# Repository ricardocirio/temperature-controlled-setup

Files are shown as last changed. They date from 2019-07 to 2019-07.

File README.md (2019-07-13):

# Temperature controlled setup

## About

This repository contains documentation for assembling a low-cost heating system designed for manufacturing and characterization of gas sensors, including dedicated hardware and firmware, comprising a proportional-integral-derivative controller and user interface for its use. The hardware consists of a printed circuit board containing an analog-to-digital converter (LTC2439) for temperature measurements acquired by thermocouples and a microcontroller (ATmega328P) that coordinates the entire process running a finite-state machine.

## Hardware

Full schematics may be found [here](./hardware/schematics.pdf). PCB's Kicad project is under the *hardware* folder.

<p align="center" float="left">
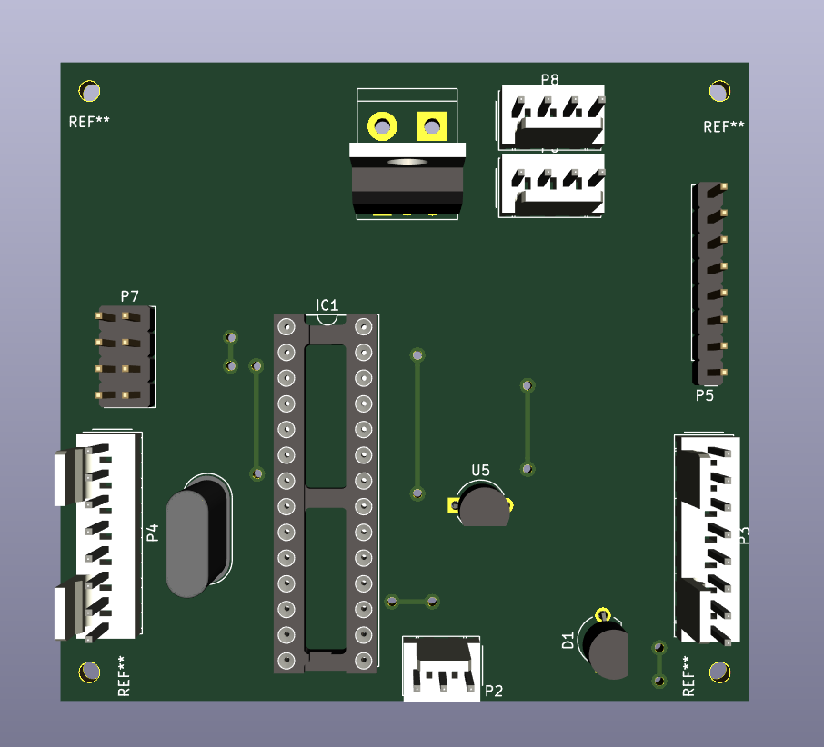
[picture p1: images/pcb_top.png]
PCB top
	
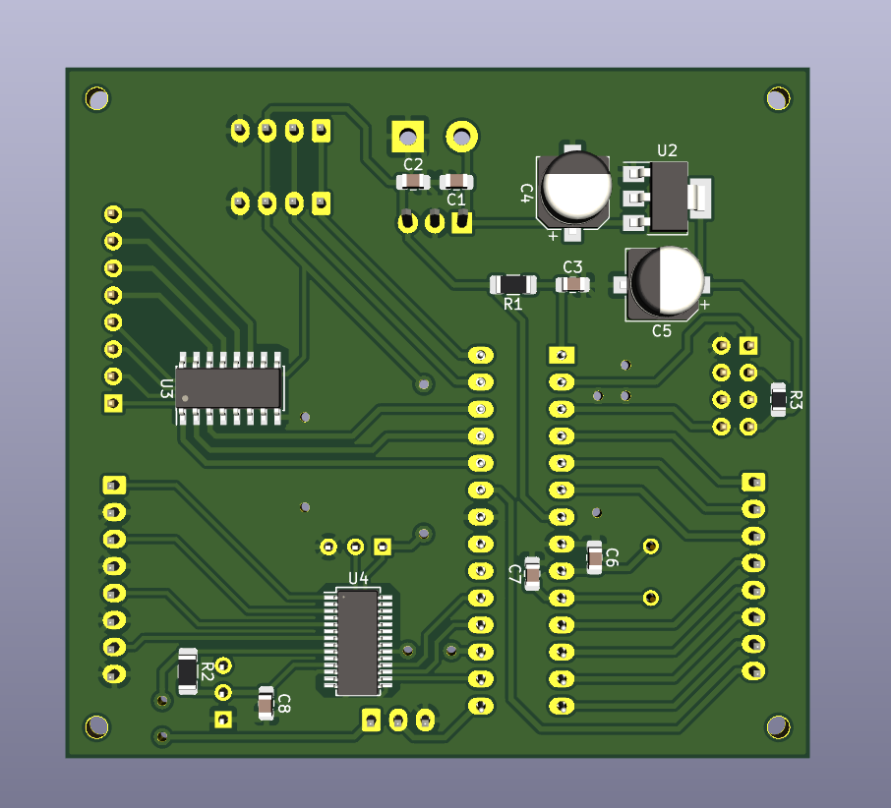
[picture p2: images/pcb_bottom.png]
PCB bottom
	
</p>

## Authors

* Ricardo Cirio<br>
* Leticia Matos<br>
* Fernando Miranda<br>
* Daniel Lohmann

Sponsor: CNPq n° 04/2018.



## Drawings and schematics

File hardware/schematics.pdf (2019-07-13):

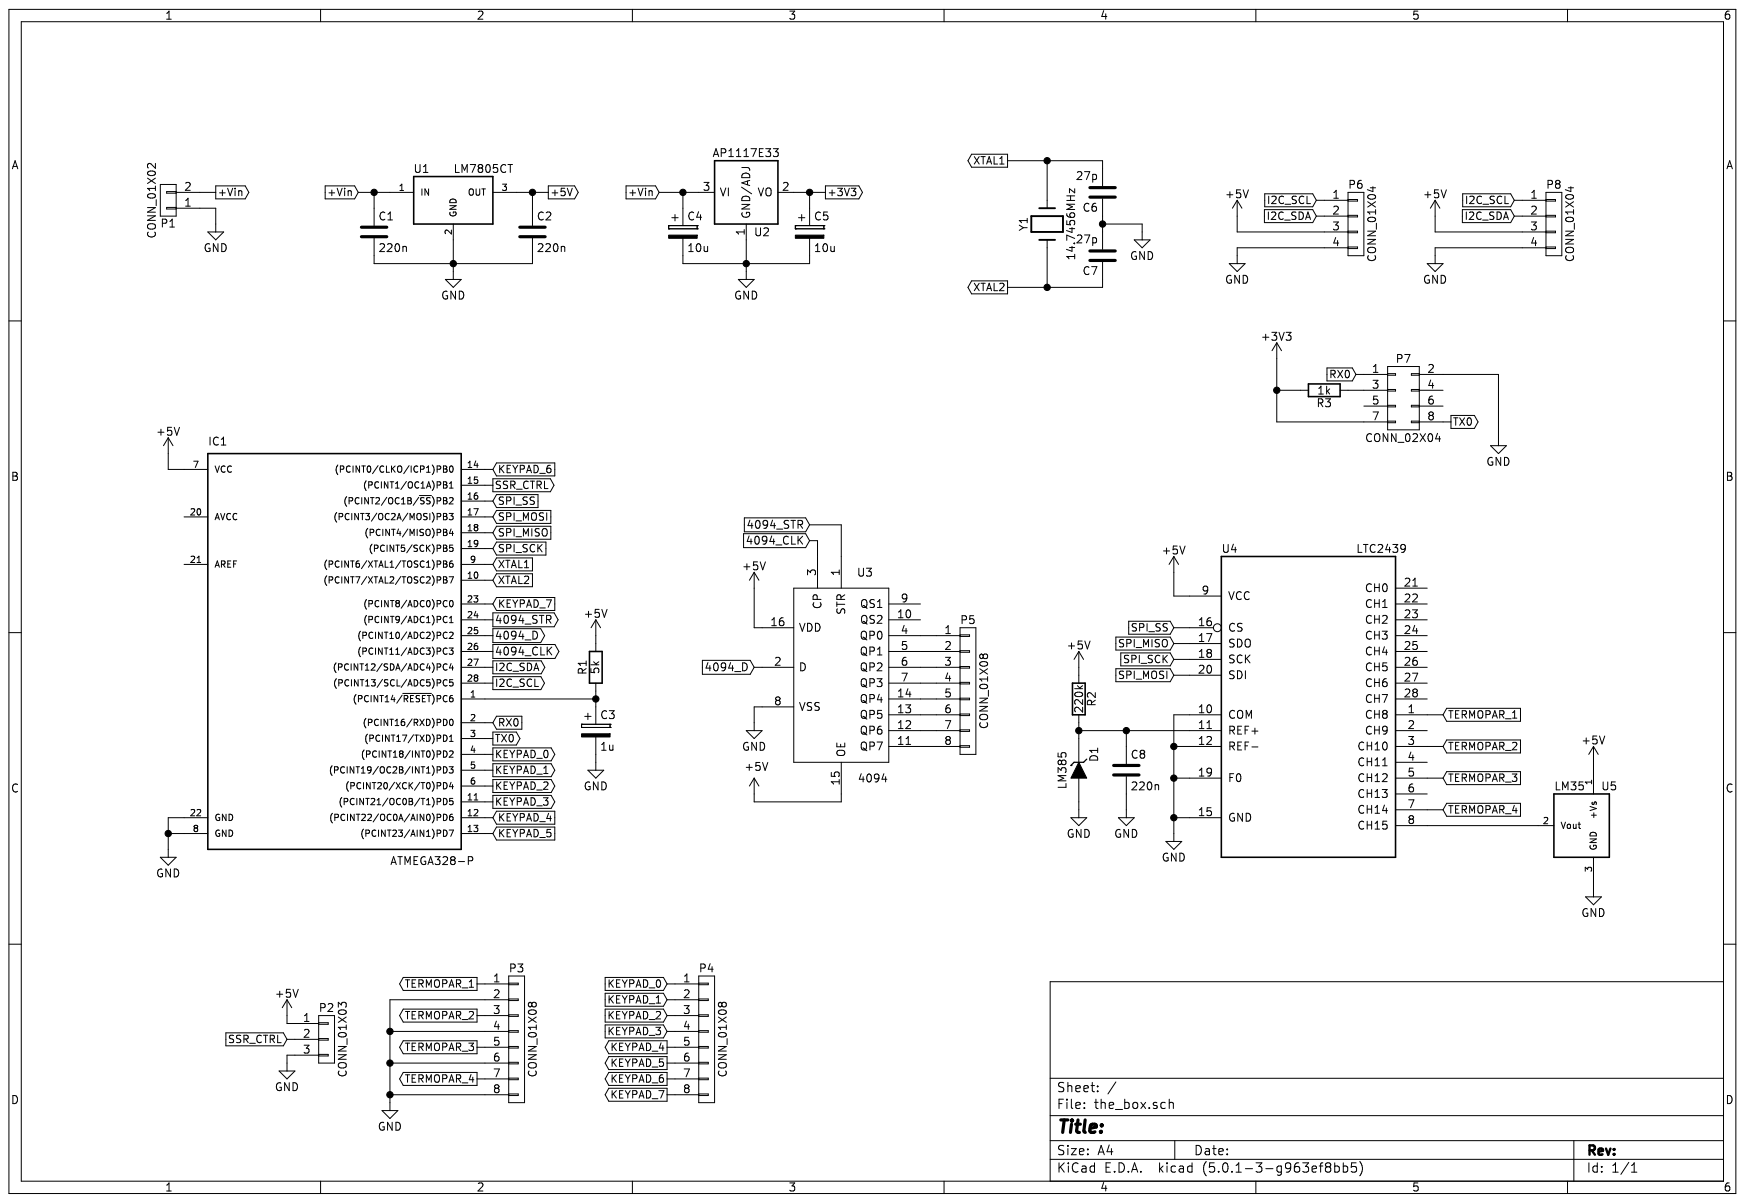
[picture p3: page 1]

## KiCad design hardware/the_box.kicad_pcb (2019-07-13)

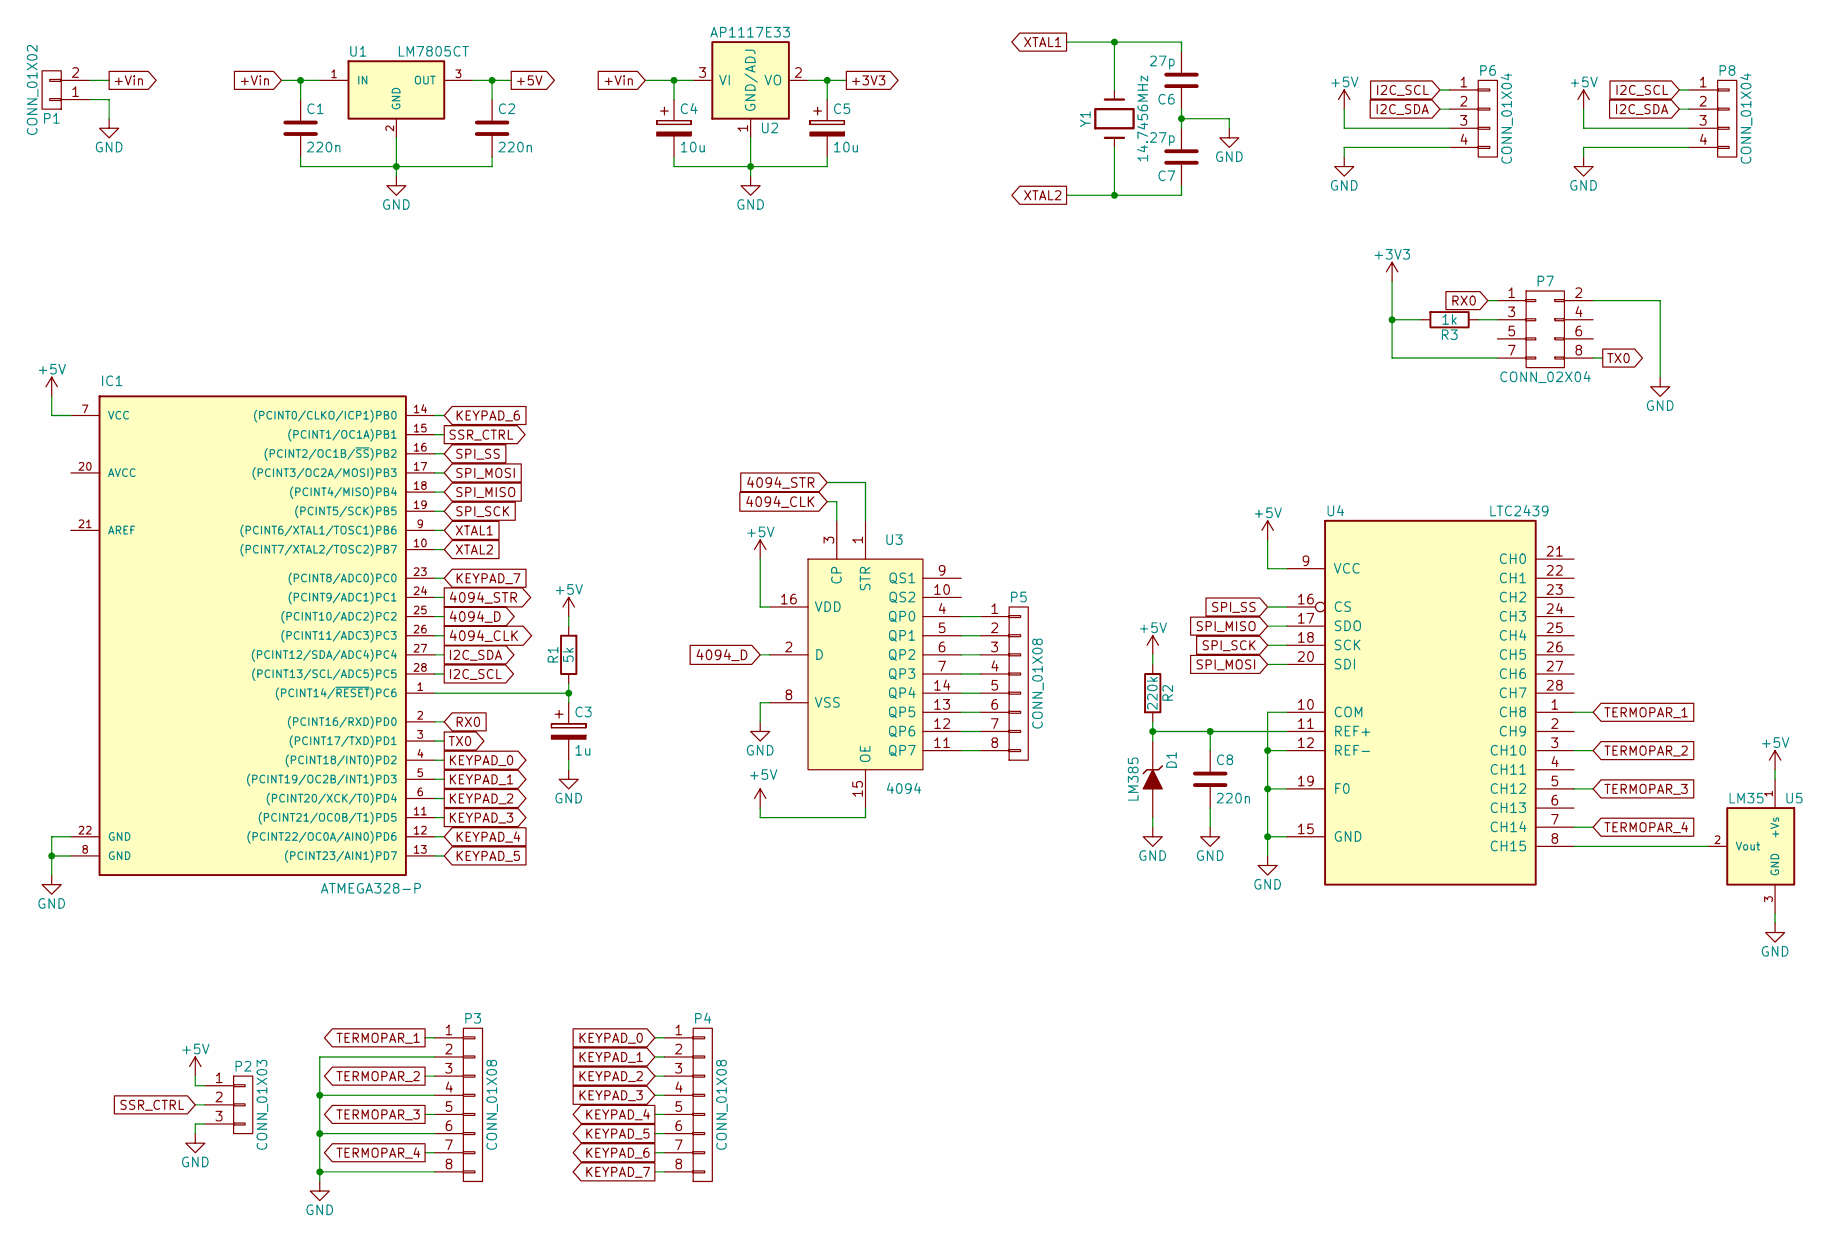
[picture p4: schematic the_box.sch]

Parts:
C1, C2, C8: 220n; C_0805_2012Metric_Pad1.15x1.40mm_HandSolder
C3: 1u; C_0805_2012Metric_Pad1.15x1.40mm_HandSolder
C4, C5: 10u; CP_Elec_6.3x5.3
C6, C7: 27p; C_0805_2012Metric_Pad1.15x1.40mm_HandSolder
D1: LM385; TO-92_Inline_Wide
IC1: ATMEGA328-P; DIP-28_W7.62mm_Socket_LongPads
P1: CONN_01X02; TerminalBlock_bornier-2_P5.08mm
P2: CONN_01X03; Molex_KK-254_AE-6410-03A_1x03_P2.54mm_Vertical
P3, P4: CONN_01X08; Molex_KK-254_AE-6410-08A_1x08_P2.54mm_Vertical
P5: CONN_01X08; PinHeader_1x08_P2.54mm_Vertical
P6, P8: CONN_01X04; Molex_KK-254_AE-6410-04A_1x04_P2.54mm_Vertical
P7: CONN_02X04; PinHeader_2x04_P2.54mm_Vertical
R1: 5k; R_1206_3216Metric_Pad1.42x1.75mm_HandSolder
R2: 220k; R_1206_3216Metric_Pad1.42x1.75mm_HandSolder
R3: 1k; R_0805_2012Metric_Pad1.15x1.40mm_HandSolder
U1: LM7805CT; TO-220-3_Vertical
U2: AP1117E33; SOT-223-3_TabPin2
U3: 4094; SOIC-16_3.9x9.9mm_P1.27mm
U4: LTC2439; SSOP-28_3.9x9.9mm_P0.635mm
U5: LM35; TO-92_Inline_Wide
Y1: 14.7456MHz; Crystal_HC49-U_Vertical

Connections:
4094_CLK: IC1.26 ((PCINT11/ADC3)PC3), U3.3 (CP)
4094_D: IC1.25 ((PCINT10/ADC2)PC2), U3.2 (D)
4094_STR: IC1.24 ((PCINT9/ADC1)PC1), U3.1 (STR)
+3V3: C5.1, P7.7, R3.2, U2.2 (VO)
+5V: C2.1, IC1.7 (VCC), P2.1, P6.3, P8.3, R1.2, R2.1, U1.3 (OUT), U3.15 (OE), U3.16 (VDD), U4.9 (VCC), U5.1 (+Vs)
+Vin: C1.1, C4.1, P1.2, U1.1 (IN), U2.3 (VI)
GND: C1.2, C2.2, C3.2, C4.2, C5.2, C6.1, C7.2, C8.2, D1.1 (A), IC1.8 (GND), IC1.22 (GND), P1.1, P2.3, P3.2, P3.4, P3.6, P3.8, P6.4, P7.2, P8.4, U1.2 (GND), U2.1 (GND/ADJ), U3.8 (VSS), U4.10 (COM), U4.12 (REF-), U4.15 (GND), U4.19 (F0), U5.3 (GND)
I2C_SCL: IC1.28 ((PCINT13/SCL/ADC5)PC5), P6.1, P8.1
I2C_SDA: IC1.27 ((PCINT12/SDA/ADC4)PC4), P6.2, P8.2
KEYPAD_0: IC1.4 ((PCINT18/INT0)PD2), P4.1
KEYPAD_1: IC1.5 ((PCINT19/OC2B/INT1)PD3), P4.2
KEYPAD_2: IC1.6 ((PCINT20/XCK/T0)PD4), P4.3
KEYPAD_3: IC1.11 ((PCINT21/OC0B/T1)PD5), P4.4
KEYPAD_4: IC1.12 ((PCINT22/OC0A/AIN0)PD6), P4.5
KEYPAD_5: IC1.13 ((PCINT23/AIN1)PD7), P4.6
KEYPAD_6: IC1.14 ((PCINT0/CLKO/ICP1)PB0), P4.7
KEYPAD_7: IC1.23 ((PCINT8/ADC0)PC0), P4.8
unnamed: C3.1, IC1.1 ((PCINT14/~RESET~)PC6), R1.1
unnamed: C8.1, D1.2 (K), R2.2, U4.11 (REF+)
unnamed: P5.1, U3.4 (QP0)
unnamed: P5.2, U3.5 (QP1)
unnamed: P5.3, U3.6 (QP2)
unnamed: P5.4, U3.7 (QP3)
unnamed: P5.5, U3.14 (QP4)
unnamed: P5.6, U3.13 (QP5)
unnamed: P5.7, U3.12 (QP6)
unnamed: P5.8, U3.11 (QP7)
unnamed: P7.3, R3.1
unnamed: U4.8 (CH15), U5.2 (Vout)
RX0: IC1.2 ((PCINT16/RXD)PD0), P7.1
SPI_MISO: IC1.18 ((PCINT4/MISO)PB4), U4.17 (SDO)
SPI_MOSI: IC1.17 ((PCINT3/OC2A/MOSI)PB3), U4.20 (SDI)
SPI_SCK: IC1.19 ((PCINT5/SCK)PB5), U4.18 (SCK)
SPI_SS: IC1.16 ((PCINT2/OC1B/~SS~)PB2), U4.16 (CS)
SSR_CTRL: IC1.15 ((PCINT1/OC1A)PB1), P2.2
TERMOPAR_1: P3.1, U4.1 (CH8)
TERMOPAR_2: P3.3, U4.3 (CH10)
TERMOPAR_3: P3.5, U4.5 (CH12)
TERMOPAR_4: P3.7, U4.7 (CH14)
TX0: IC1.3 ((PCINT17/TXD)PD1), P7.8
XTAL1: C6.2, IC1.9 ((PCINT6/XTAL1/TOSC1)PB6), Y1.2
XTAL2: C7.1, IC1.10 ((PCINT7/XTAL2/TOSC2)PB7), Y1.1

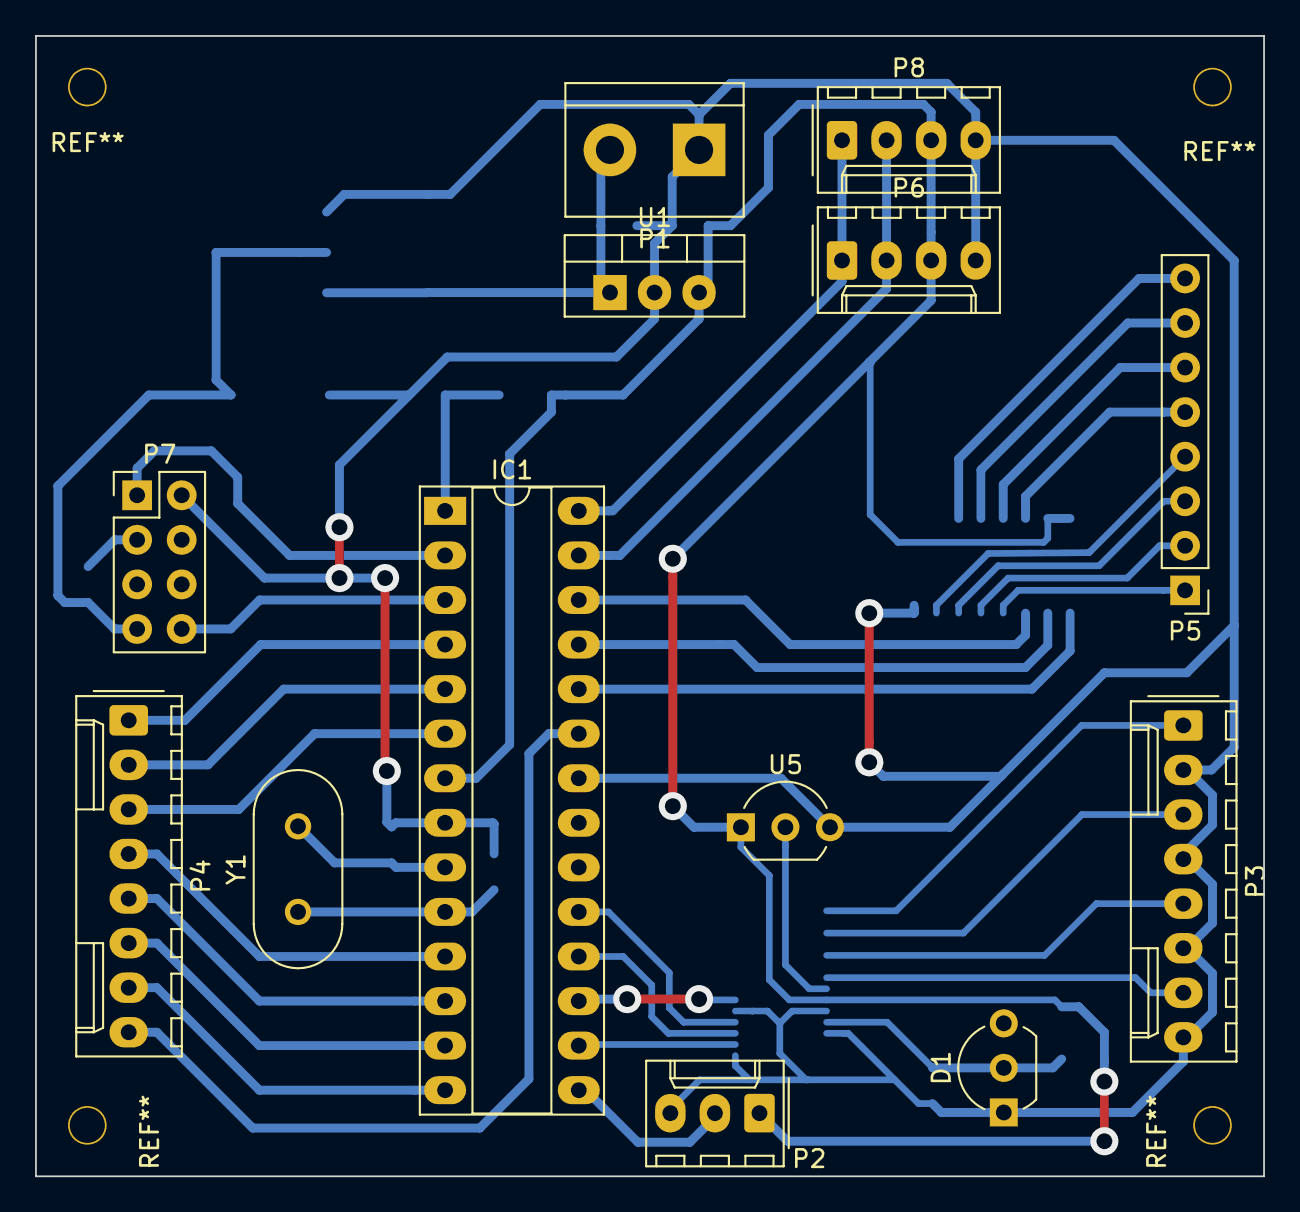
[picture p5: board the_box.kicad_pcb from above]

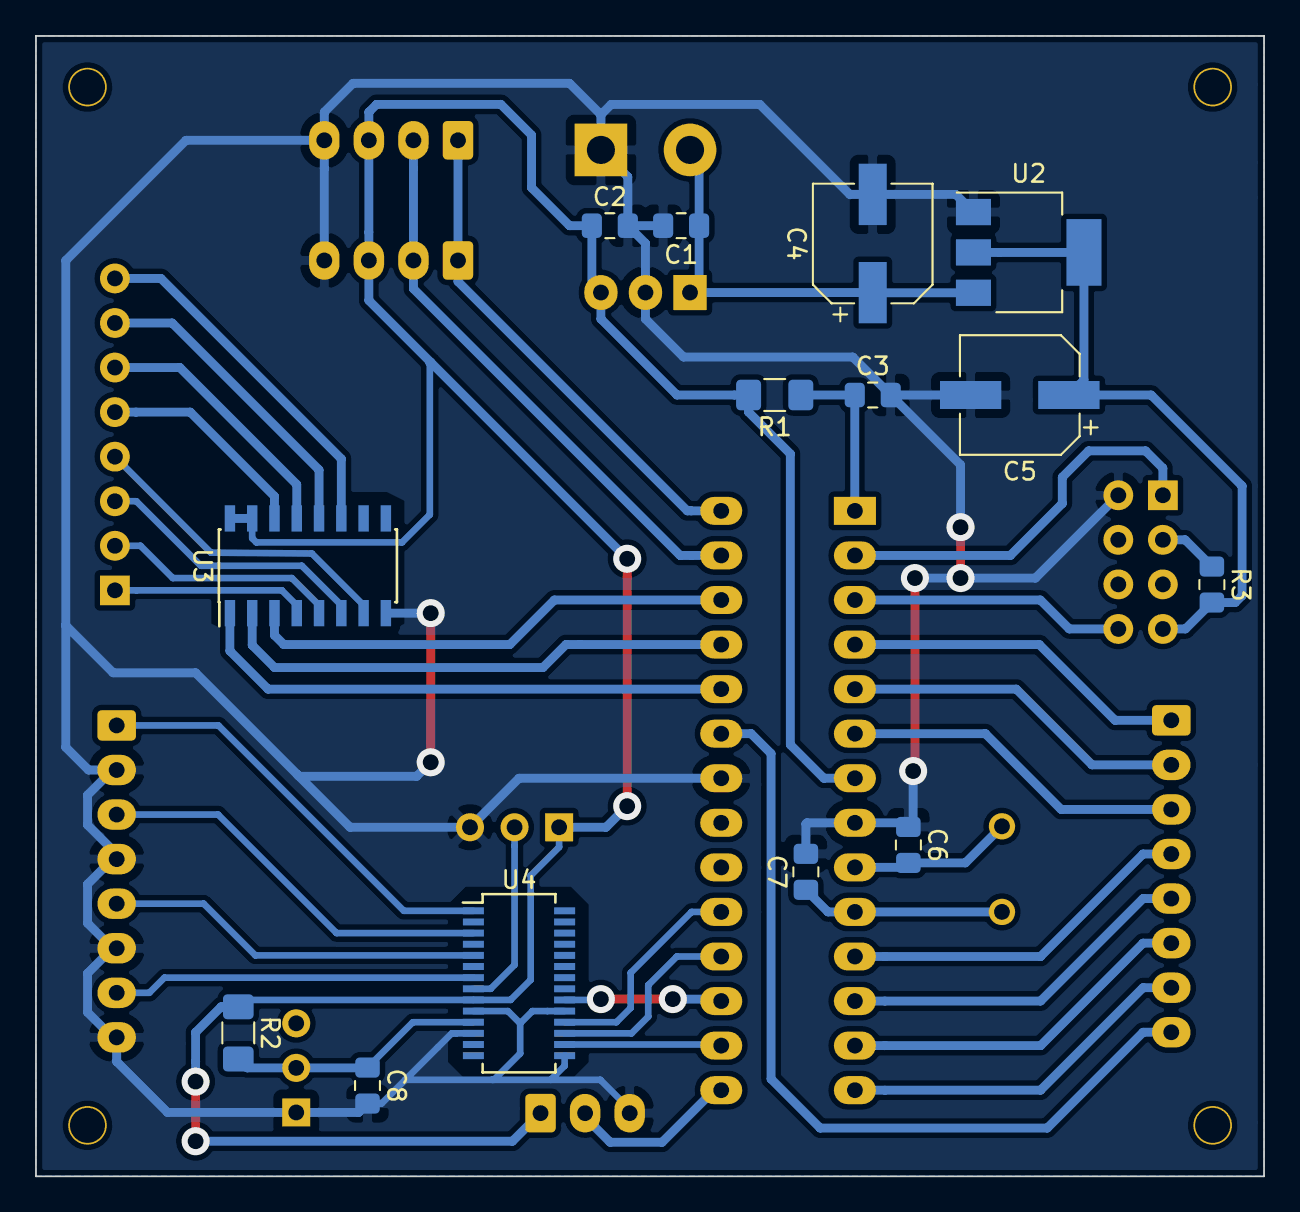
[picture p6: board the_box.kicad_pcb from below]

Board: 2 copper layers, 70.0 x 65.0 mm, 27 parts (14 on the bottom side), 42 nets.
